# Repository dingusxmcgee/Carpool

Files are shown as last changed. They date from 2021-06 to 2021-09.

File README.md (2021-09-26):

# Carpool

## Carpool is an open source, multi-mount, minivan PCB compatible keyboard case.

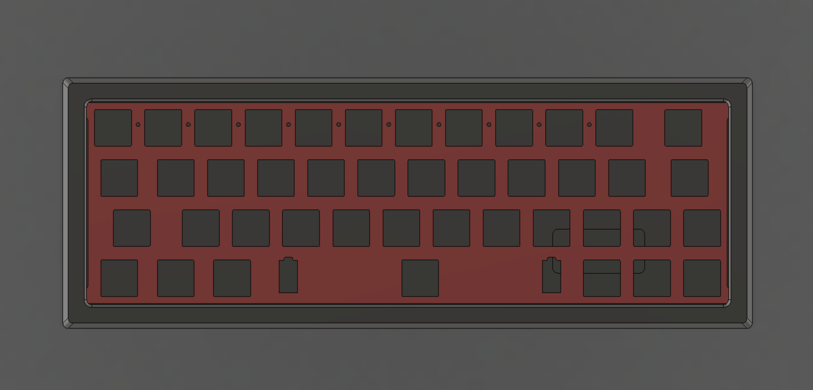
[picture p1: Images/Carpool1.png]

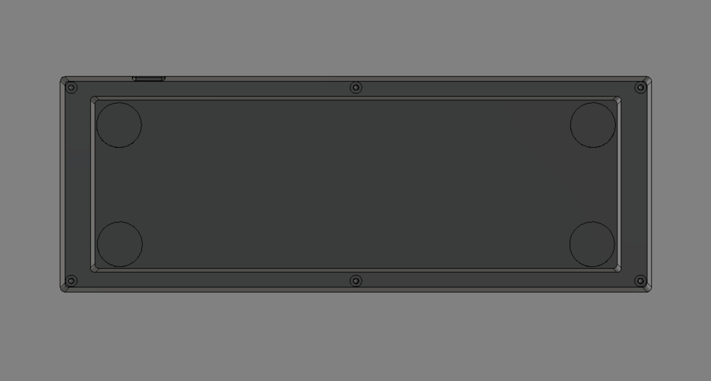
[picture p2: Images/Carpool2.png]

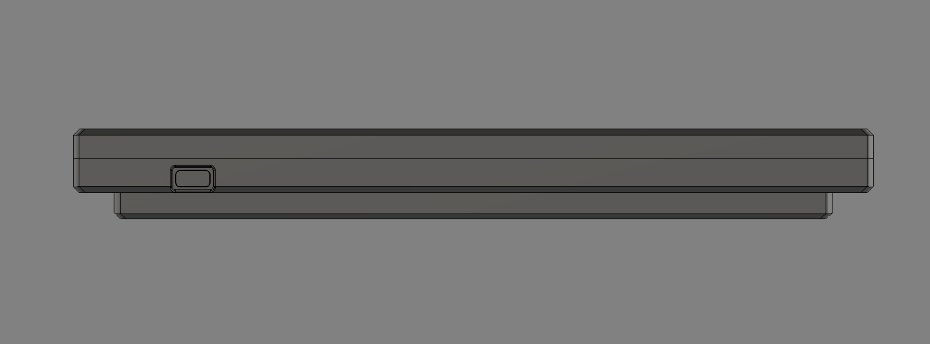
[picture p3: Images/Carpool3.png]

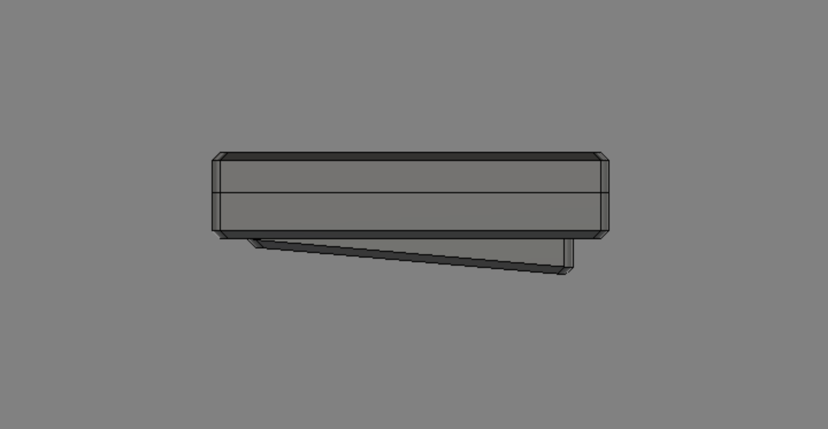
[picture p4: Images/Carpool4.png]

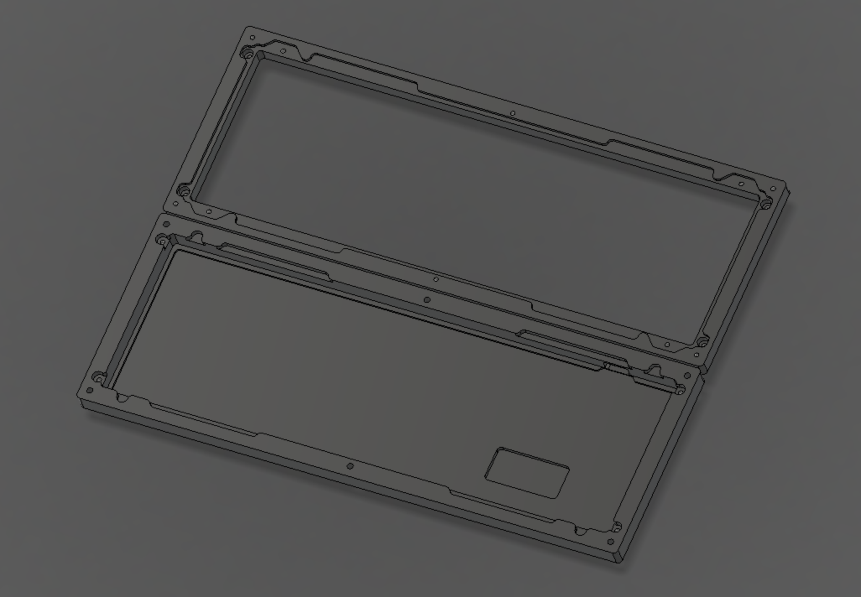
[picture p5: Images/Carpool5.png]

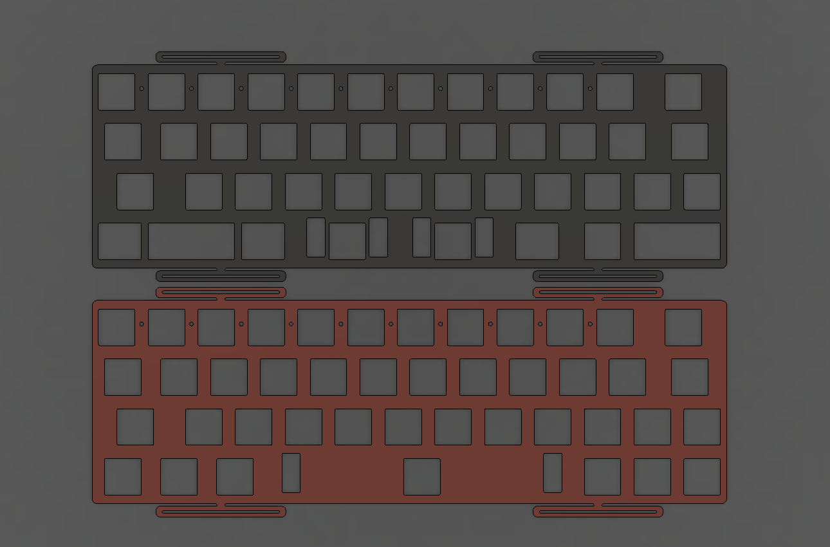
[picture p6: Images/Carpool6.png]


Carpool is designed to be used in the following ways:
 
* Coriander Plate: Top Mount
* Hull Plate: Top Mount
* Hull Plate: Bottom Mount
* Custom 'Leafspring Plates': Sandwich Mount

Carpool features a 2 piece case design, optional 5deg angle, cutout for a small battery(Airport Shuttle PCB support) and is compatible with all minivan or minivan inspired pcbs that fit within the approximately 243mmx76mm pcb size(except Sketch).

With optional 5deg angle, front height is 22.3mm. Without, it is 21mm.
*Note that the 3DP version is 1mm taller in order to prevent a super thin bottom piece*

Bottom case is provided with both angle attached(using 3 less screws) and detached(for easier 3D printing). Bottom is designed for 19mm cork bumpons (like these https://www.amazon.com/Rockler-Self-Adhesive-Cork-Dots/dp/B001GH7JXW). You also have the option to reverse the separate Angle piece to acheive a -5deg angle.

Carpool uses the following screws to piece it all together: 
 * Bottom case to top case: m2.5 - sockethead or smaller - 8-11mm (6x)
 * Hull bottom mount plate: m2.5 - sockethead or smaller -  6-8mm (4x)
 * Hull top mount plate: m2.5 - sockethead or smaller - 6-8mm (4x)
 * Coriander top mount plate: m2.5 - sockethead or smaller - 4-6mm (4x)
 * Bottom case to separate angle: m2.5 - sockethead or smaller (pan or button head will fit better here due to limited material in bottom case) - 2-4mm (4x)

*Please note that the 'Leafspring plates' are only partially tested, so your mileage may vary.  It is important to note that extremely flexible materials like IMA may not be suitable to this case. If you would like to see some added or have some modification suggestions, submit a PR or reach out to me on discord @dingusxmcgee_#1691*

*All files are provided as is and I accept no liability if they aren't very good.*

*Licensed with Unlicense*

If you would like to support me in some way, consider [buying me a coffee :)](https://www.buymeacoffee.com/dingusxmcgee)

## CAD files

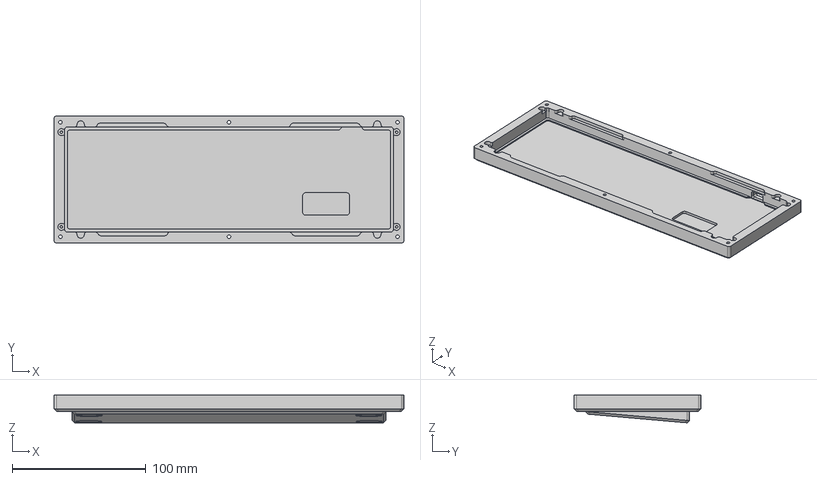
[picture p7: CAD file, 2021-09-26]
3D Print Version/STEPs/Carpool-BottomFull-3DP.step
261.9 x 95.2 x 20.8 mm

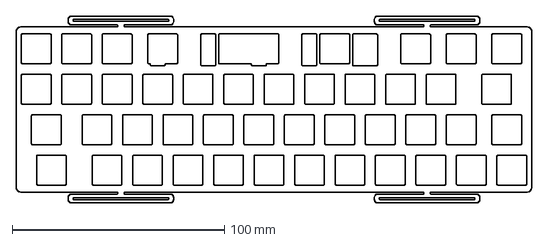
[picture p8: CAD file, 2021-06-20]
DXFs/Carpool-Leafplate-Minisub.dxf
242.6 x 87.8 mm

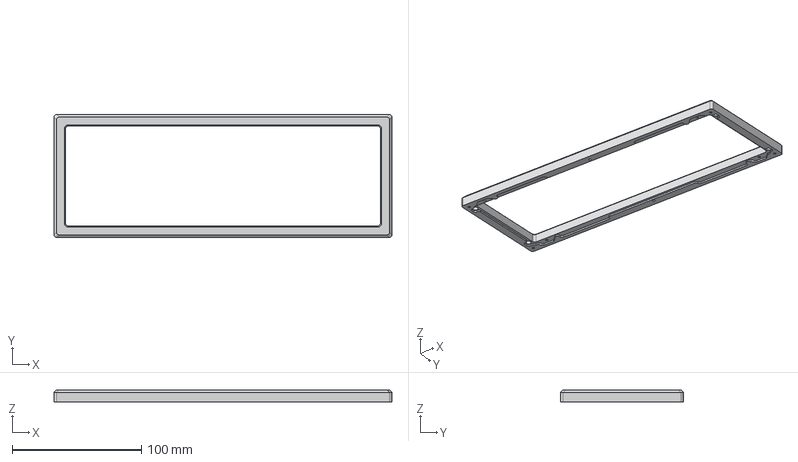
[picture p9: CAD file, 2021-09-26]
STEPs/Carpool-Top.step
261.9 x 95.2 x 9.60 mm

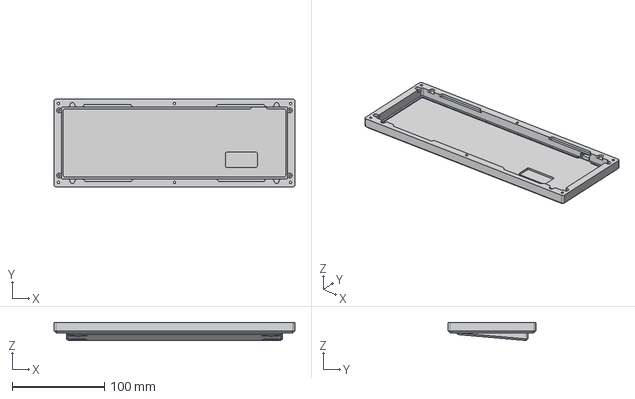
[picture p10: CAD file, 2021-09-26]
STEPs/Carpool-Bottom-IntAngle.step
261.9 x 95.2 x 19.8 mm

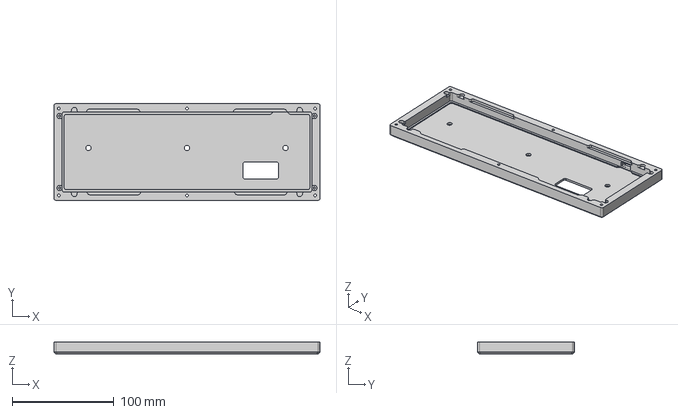
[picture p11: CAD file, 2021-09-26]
3D Print Version/STEPs/Carpool-Bottom-3DP.step
261.9 x 95.2 x 12.3 mm

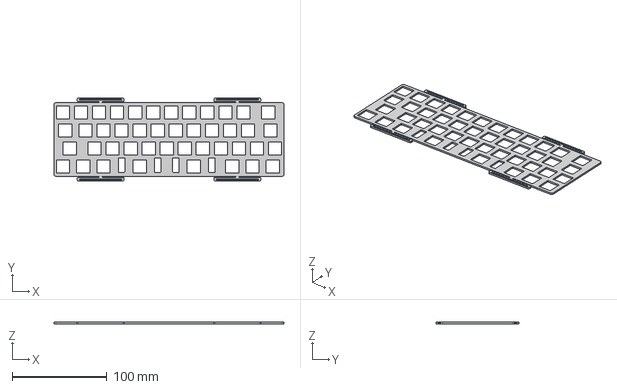
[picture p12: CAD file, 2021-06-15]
STEPs/Carpool-Leafplate-M3n3van.step
242.6 x 87.8 x 1.60 mm

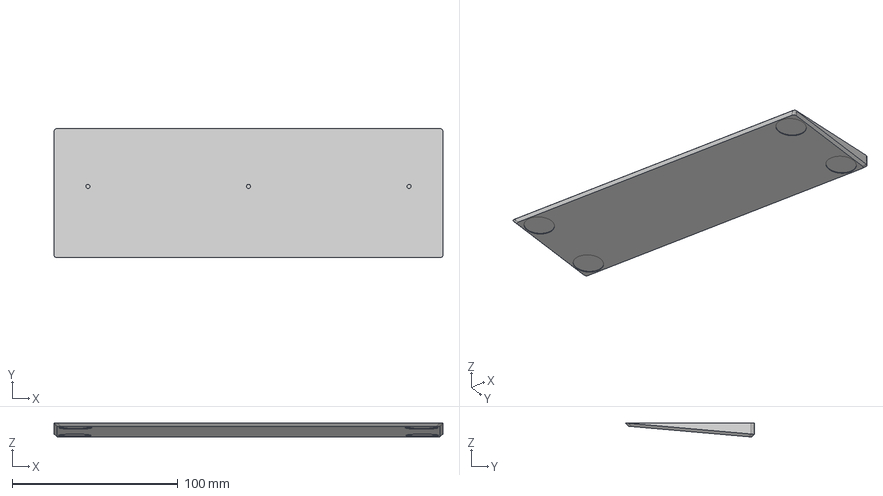
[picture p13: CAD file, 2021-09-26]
3D Print Version/STEPs/Carpool-Angle-3DP.step
235.0 x 78.0 x 8.50 mm

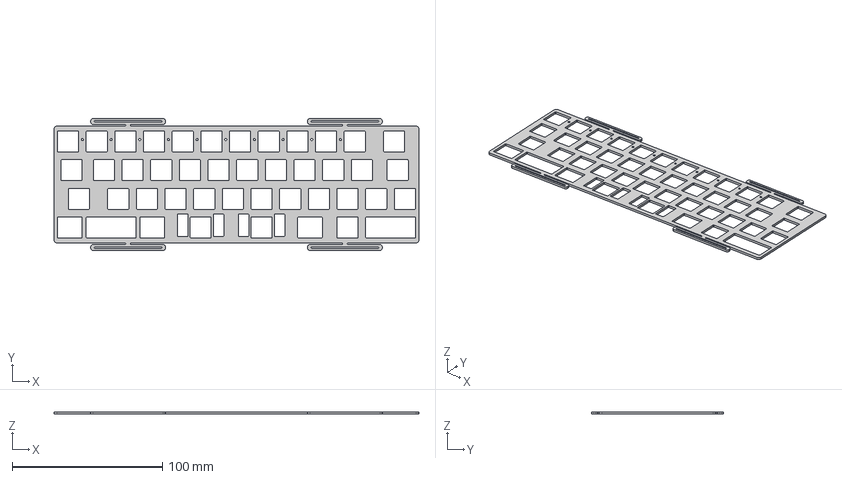
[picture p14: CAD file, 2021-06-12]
STEPs/Carpool-Leafplate-Splitspace.step
242.6 x 87.8 x 1.60 mm

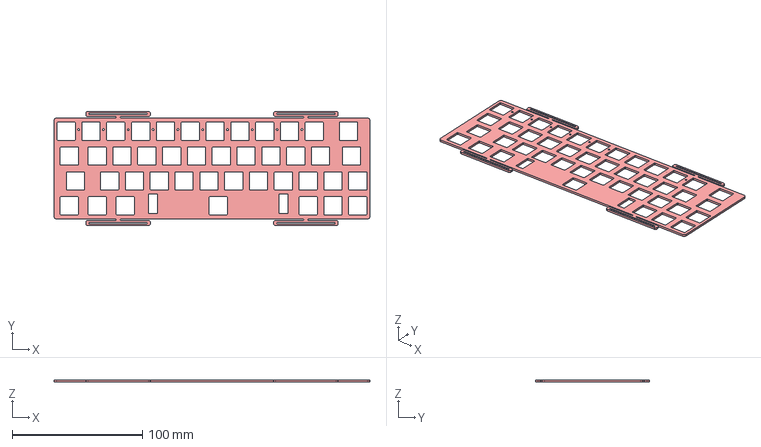
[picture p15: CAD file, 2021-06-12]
STEPs/Carpool-Leafplate-Jetvan.step
242.6 x 87.8 x 1.60 mm

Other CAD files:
3D Print Version/STEPs/Carpool-Top-3DP.step
3D Print Version/STLs/Carpool-Angle-3DP.stl
3D Print Version/STLs/Carpool-Top-3DP.stl
DXFs/Carpool-Leafplate-Jetvan.dxf
DXFs/Carpool-Leafplate-M3n3van.dxf
DXFs/Carpool-Leafplate-SplitSpace.dxf

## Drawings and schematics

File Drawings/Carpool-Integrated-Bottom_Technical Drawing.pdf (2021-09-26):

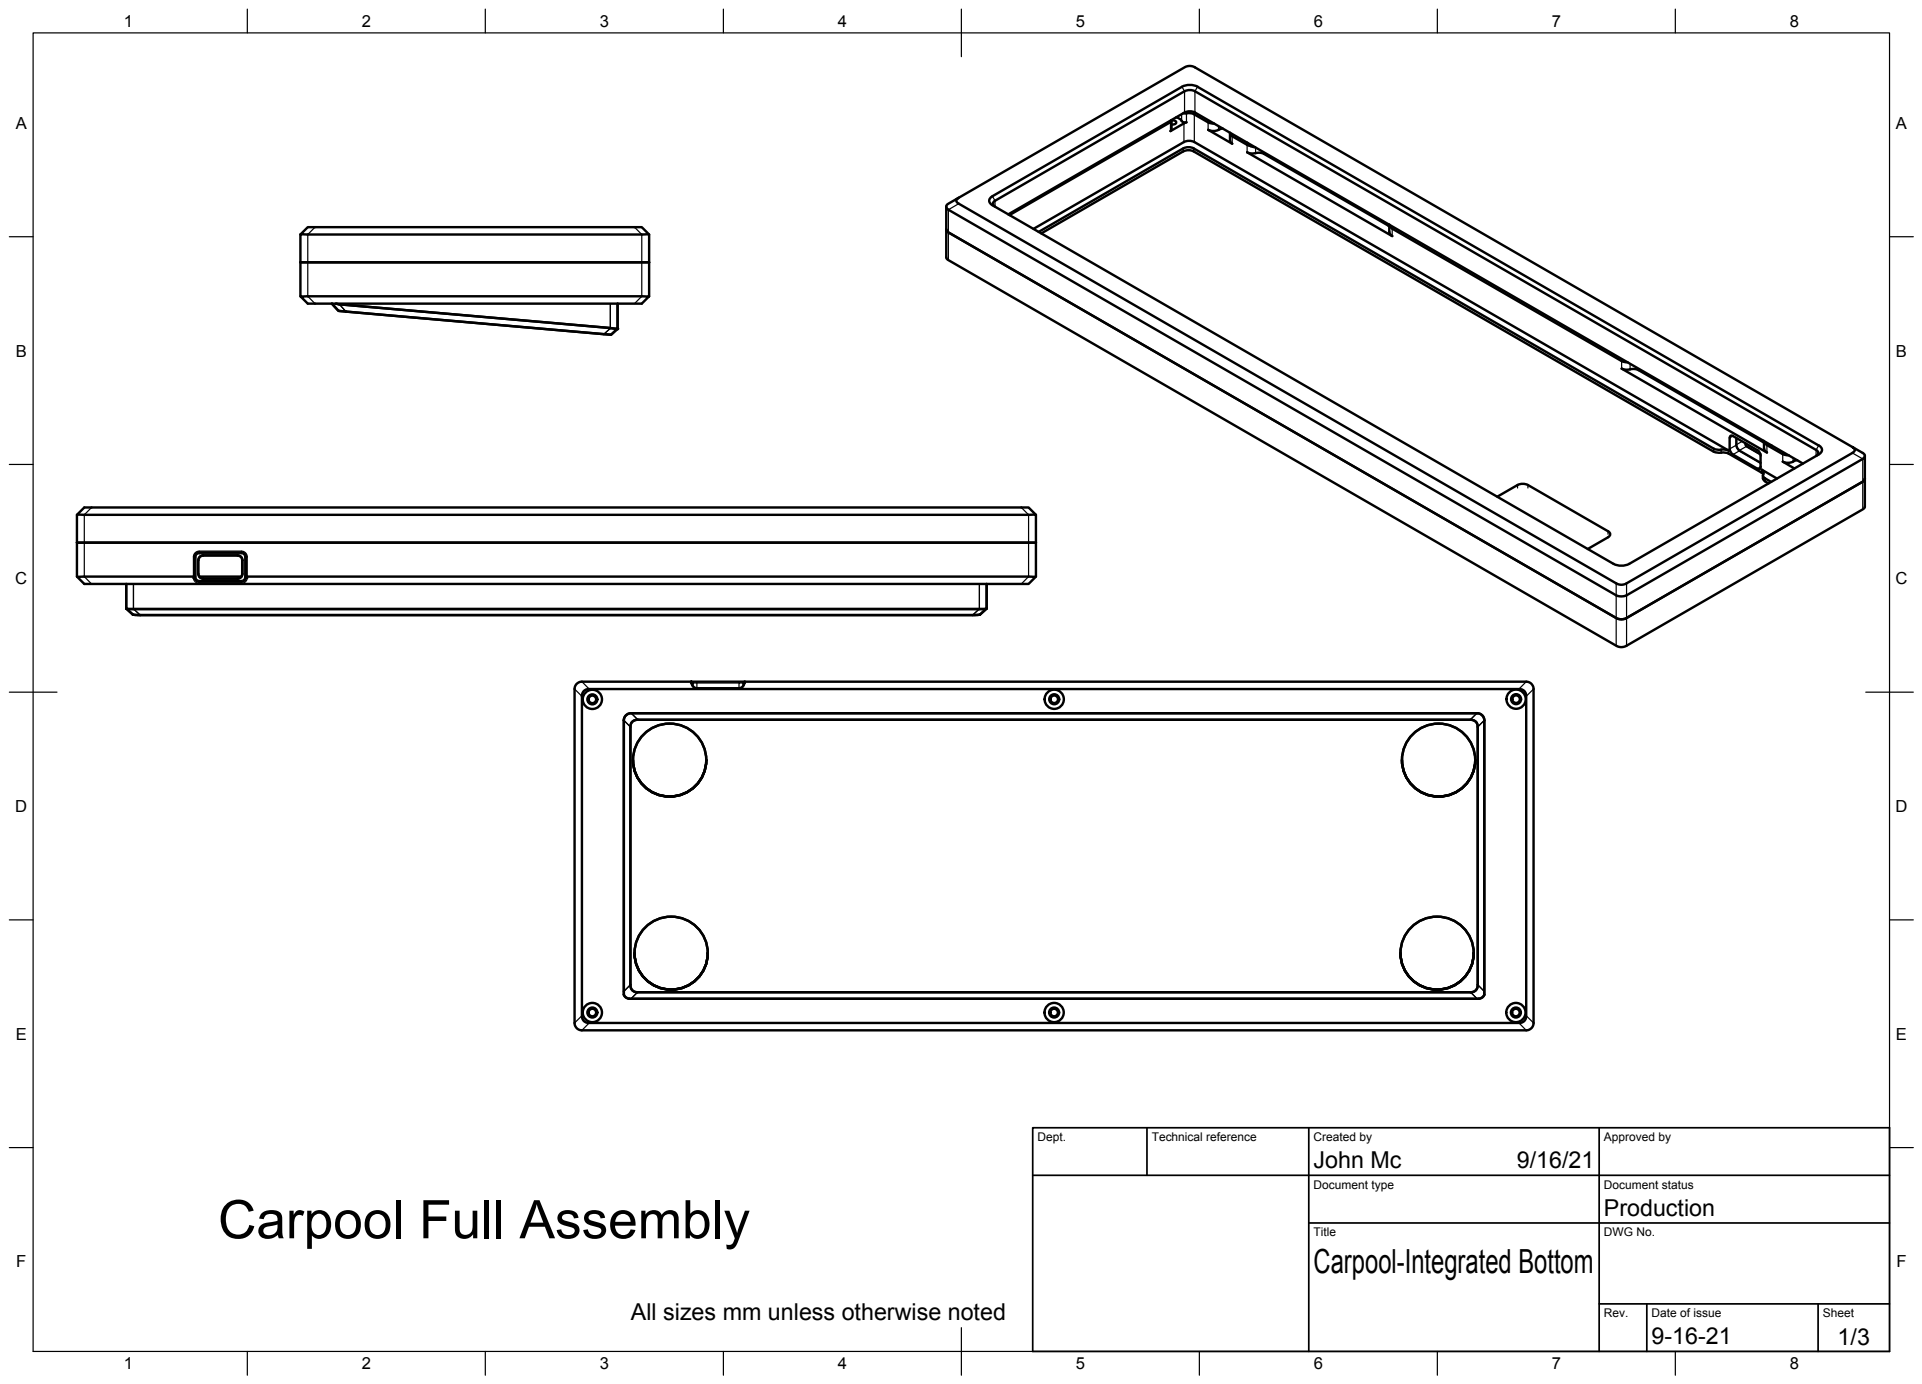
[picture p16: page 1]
Title; DWG No.; Rev.; Date of issue; Sheet

Dept. | Technical reference | Created by John Mc 9/16/21 | Approved by

Document type | Document status Production

Carpool Full Assembly

Carpool-Integrated Bottom

All sizes mm unless otherwise noted

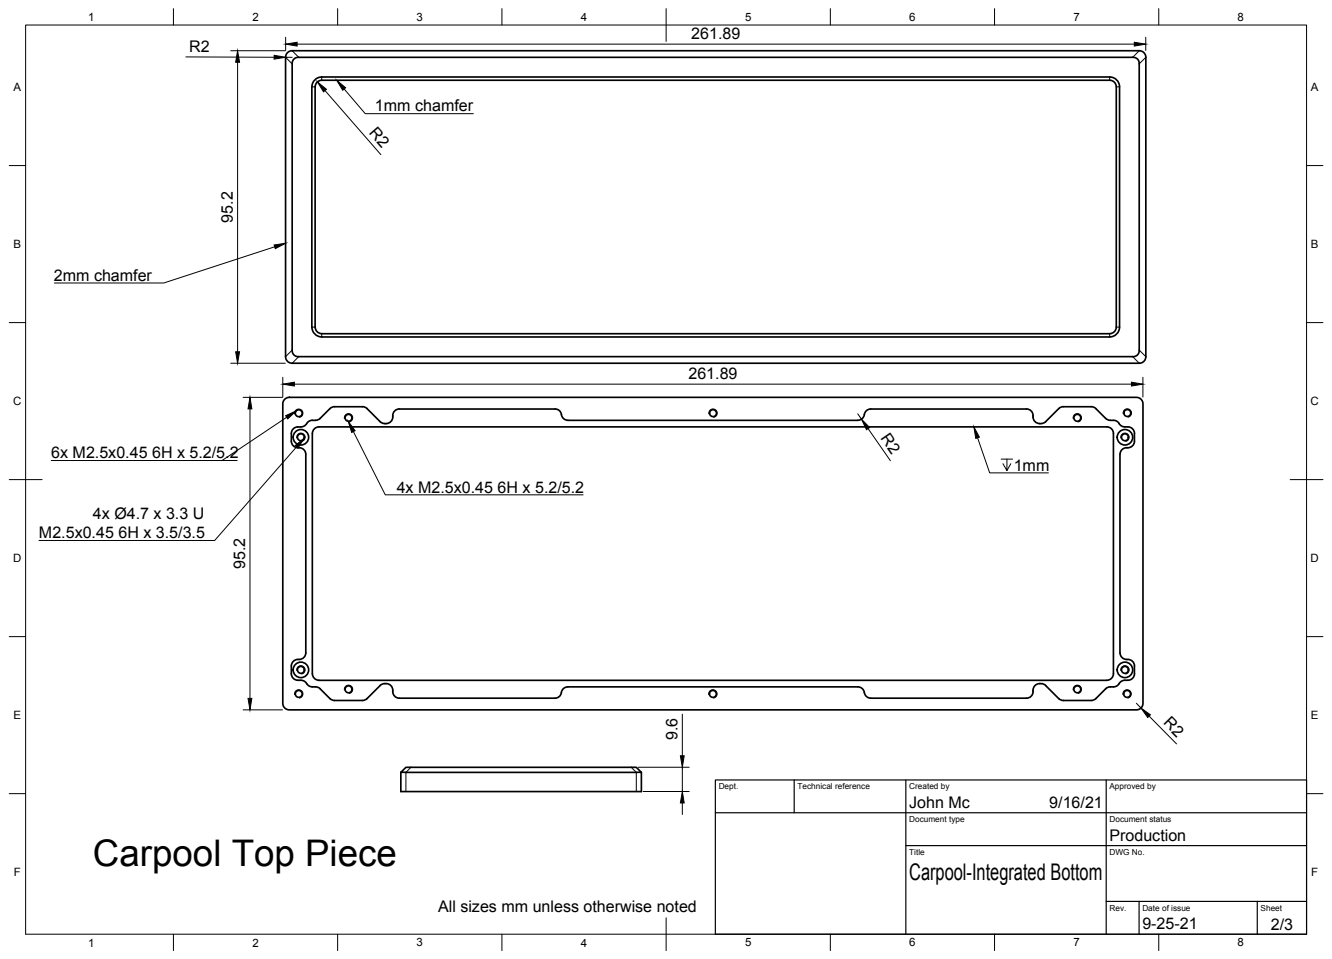
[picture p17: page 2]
Title; DWG No.; 1mm chamfer; 2mm chamfer

Dept. | Technical reference | Created by John Mc 9/16/21 | Approved by

Document type | Document status Production

Carpool Top Piece

Carpool-Integrated Bottom

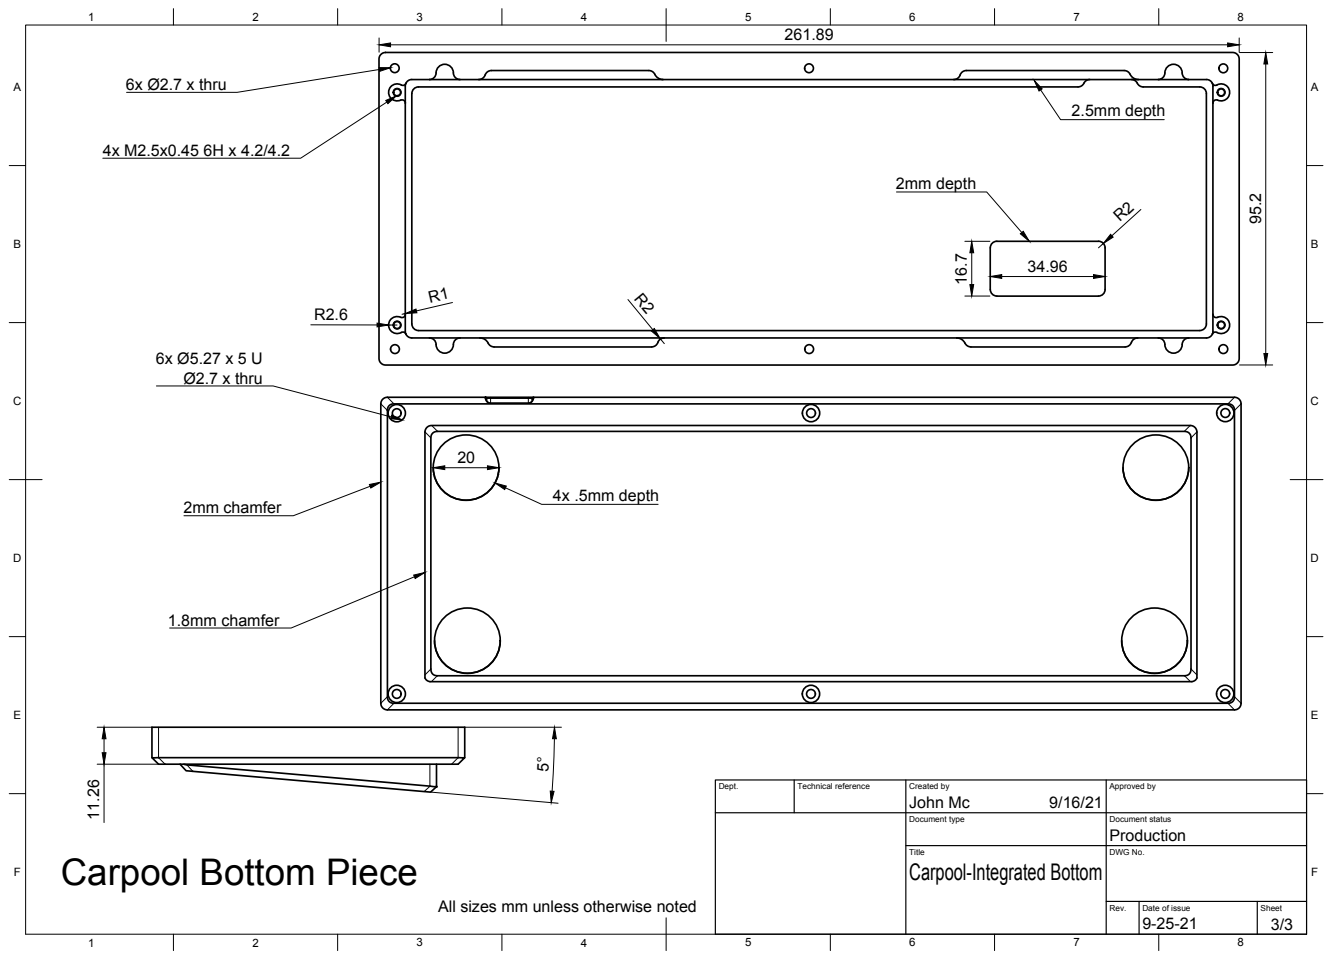
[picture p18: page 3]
Title; DWG No.; 2mm chamfer; 2mm depth; 2.5mm depth; 6x Ø2.7 x thru; Ø2.7 x thru 11.26; 1.8mm chamfer; 4x .5mm depth

Dept. | Technical reference | Created by John Mc 9/16/21 | Approved by

Document type | Document status Production

Carpool-Integrated Bottom

Carpool Bottom Piece

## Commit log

2021-06-12 Update leaf plate, commit case files
    [Carpool-Angle.step, Carpool-Angle.stl, Carpool-Bottom-IntAngle.step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]
2021-06-12 Thread holes in STEPs and add drawings
    [Carpool-Angle.step, Carpool-Bottom-IntAngle.step, Carpool-Bottom.step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]
2021-06-15 Add M3n3van leaf plate
    [Carpool-FullStep.step, Carpool-Leafplate-M3n3van.dxf, Carpool-Leafplate-M3n3van.step]
2021-06-20 Add Minisub Leafplate
    [Carpool-Leafplate-Minisub.dxf]
2021-07-29 Fix Threaded holes on bottom case, add dims to drawings
    [Carpool-Bottom-IntAngle.step]
2021-09-26 Improved leaf plate fit, new 3dp case
    [Carpool-Angle-3DP.step, Carpool-Angle-3DP.stl, Carpool-Angle.step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]
